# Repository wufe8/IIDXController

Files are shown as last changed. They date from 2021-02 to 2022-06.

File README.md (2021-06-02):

# IIDXController
自制iidx手台记录

## 目录
[TOC]

## 材料
1. 开发板-控制器主控  
    arduino leonardo micro pro 23RMB  
	建议还是加钱上普通的leonardo 也就贵十几二十
2. 面包板以及排母: 分别1个和2个 用于分线以及固定  
    普通的400孔面包板 2.6RMB/个
	2.54mm间距单行排母 1\*12P 0.23RMB/个
3. 按键: 4个白色33mm长按键 3个黑色33mm长按键 4个白色33mm方按键  
    普通 150RMB一套  
    三和 750RMB一套
4. 微动: 11个   
    D2MV-01-1C2 12.8RMB/个   
    D2MV-01-1C3(压力稍大) 12.8RMB/个  
    V-15-1C25(压力较大 常用于辅助键) 4.5RMB/个  
    135RMB
5. 编码器: 1个  
    npn dc5-24v 600p/r的E6B2-CWZ6C 75RMB  
6. 杜邦线: 约50条  
    1pin 2.54mm 0.15RMB/条 
    23RMB
7. 插簧(可选 也可直接焊接): 约30个 用于杜邦线与微动簧片的热插拔连接  
    2.8mm(#187端子) 或 6.3mm(#250端子) 根据使用微动的端子而定 10-15RMB/100个  
    插簧钳 35RMB 也可使用焊接 更牢固 就是比较耗时间
    > 此外 直接定制头是最省时间的方法
8. 游戏机按钮支架(买按键应该有送 不用买)&LED灯(led可选): 各11个  
	0.5-1.5RMB/个
9. 橡胶防滑垫: 4个  
	4个 22(大头)\*18(小头)\*10(高)白色 0.7RMB/个
10. 螺丝  
	4个 M3\*6 手拧 作为1p 2p切换  
	4个 M3\*20 平头 作为转盘距离切换  
	4个 M4\*6 内六角 作为防滑垫固定  
	8个 M3 螺母 备用  
	共约15RMB 有剩余螺丝
11. 外壳  
	cad绘制 5系铝带90度弯折&焊接 280RMB
	如果用单块板子然后热熔胶什么的拼接应该会便宜很多
	加上换成木板或者亚克力 成本应该可以压低至100内

--------
总计813.25RMB 含邮费 含外壳 以及买错的(xh2.54端子线 #110插簧)

> 省钱tips:
> 1. 使用便宜的微动 甚至可能可以节省100RMB以上
> 2. 编码器可以便宜一点 但不建议太缩水 大约可以节省0-35RMB
> 3. 插簧和插簧钳可以不买 使用焊接 可以节省45-55RMB
> 4. 外壳是成本大头 使用铁 塑料 甚至纸箱 可以节省50-280RMB
> 如此 尽可能缩 可能可以到350RMB

## 程序
https://github.com/lizardbeans/diy-iidx
现成开源程序 感谢@lizardbeans 大佬  
不过他提供的是普通leonardo 而我用的是pro micro 接口少些(无法同时使用完整版)  
加上我需要4个功能键 因此对代码进行了些修改(还好代码并不难而且也预料到了加按键这个需求)  
fork: https://github.com/wufe8/diy-iidx

## 贡献者
wufe8

## LICENSE 使用许可
diy-iidx需参照原作者
其余 所有模型(包括blender以及cad)都是我根据网上描述自己画的  
请勿商用 而个人使用没有问题 但如果网络中进行引用 希望可附带本网址(https://github.com/wufe8/IIDXController)

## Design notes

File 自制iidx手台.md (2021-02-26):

# 自制iidx手台记录
wufe8

## 目录
[TOC]

## 材料
1. 开发板-控制器主控
micro pro 21$
2. 按键: 4个白色33mm长按键 3个黑色33mm长按键 4个白色33mm方按键
普通 90$
星韵 150$
三和 750$
3. 弹簧: 13个 20g/60g/80g/90g
djdao 85$/10个
4. 微动: 13个  
D2MV-01-1C2 13$/个
D2MV-01-1C3(压力稍大) 13$/个
V-15-1C25(压力较大 常用于辅助键) 4.5$/个
5. 编码器: 1个
npn dc5-24v 600p/r的E6B2-CWZ6C 75$
6. 端子线: 13条
4pin 2.57mm 0.4$/个
7. 插簧: 13个
2.8mm(#187端子) 或 6.3mm(#250端子) 根据使用微动的端子而定 5$/50个
插簧钳 35$
8. 游戏机按钮支架&LED灯(led可选): 各13个
0.5-1.5$/个
9. 橡胶防滑垫
4个 22(大头)*18(小头)*10(高)白色 0.7$/个
10. 螺丝
4个 M3*6 手拧 作为1p 2p切换
4个 M3*20 平头 作为转盘距离切换
4个 M4*4 内六角 作为防滑垫固定
8个 M3 螺母 备用
共约12$

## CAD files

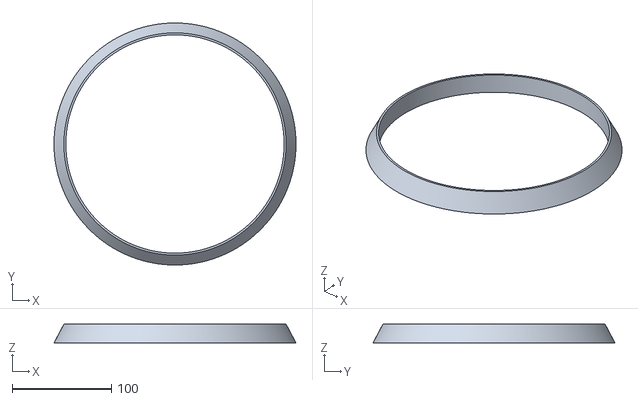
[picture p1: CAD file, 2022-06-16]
TurntableFrame.stl
244.0 x 244.0 x 19.0

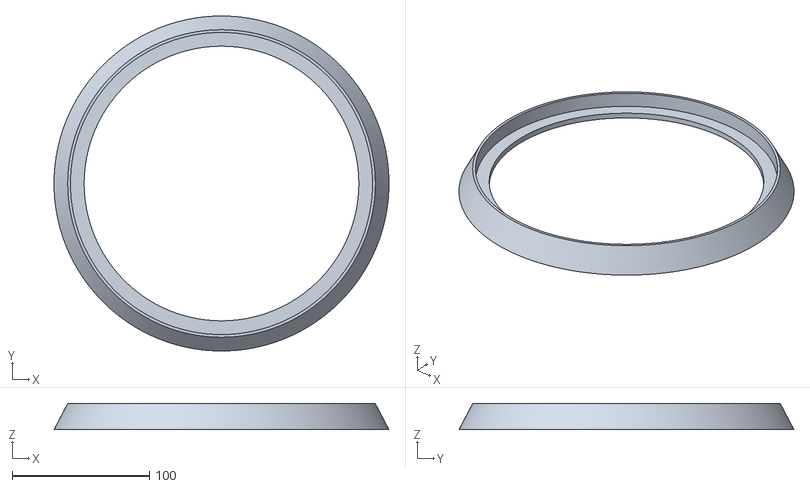
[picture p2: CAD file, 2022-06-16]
TurntableFrame(fixed).stl
244.0 x 244.0 x 19.0

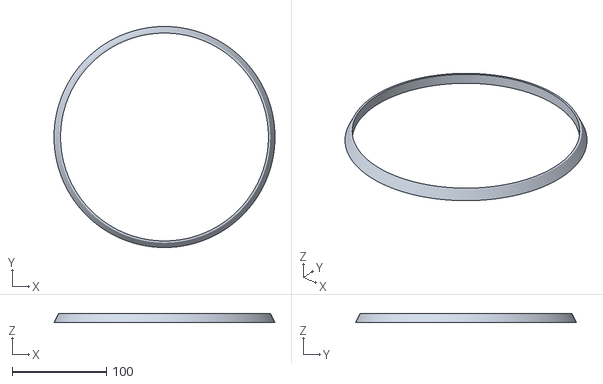
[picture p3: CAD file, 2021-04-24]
TurntableFrame(upper).stl
234.0 x 234.0 x 10.0

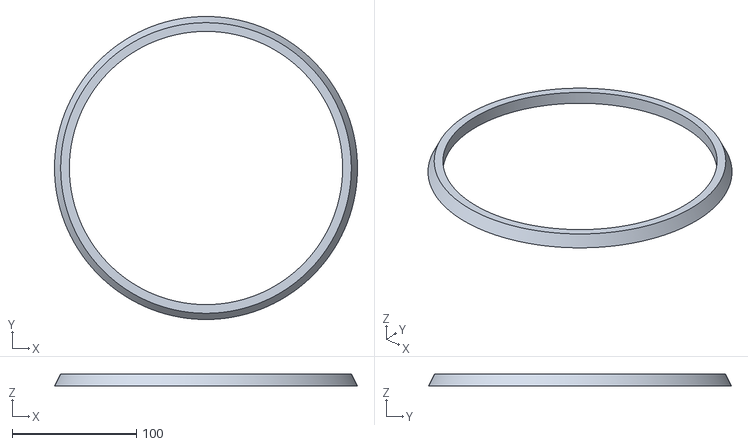
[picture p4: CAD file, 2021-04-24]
TurntableFrame(lower).stl
244.0 x 244.0 x 10.00

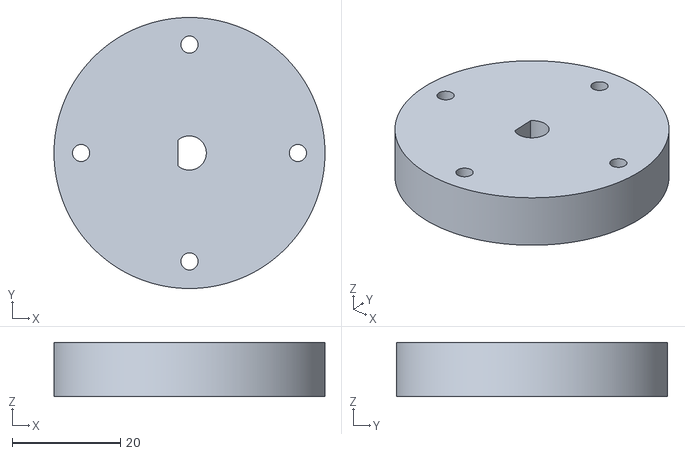
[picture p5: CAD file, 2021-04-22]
EncoderFixed.stl
50.0 x 50.0 x 10.0

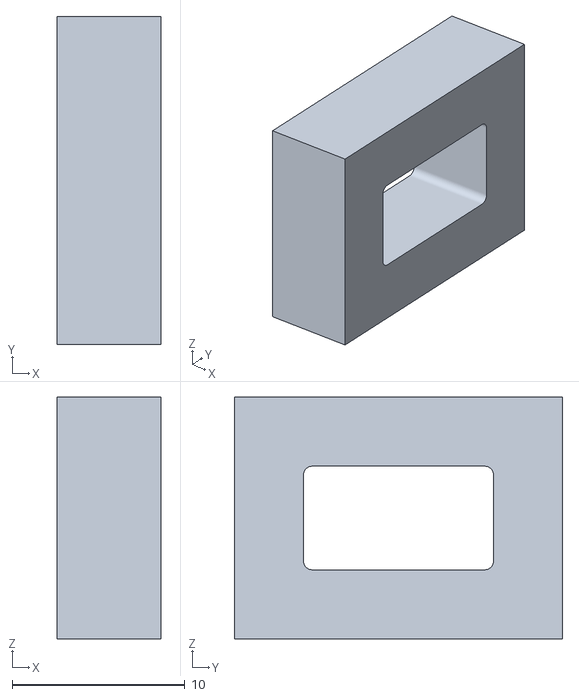
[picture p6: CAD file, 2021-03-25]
USBfixed.stl
6.00 x 19.0 x 14.0

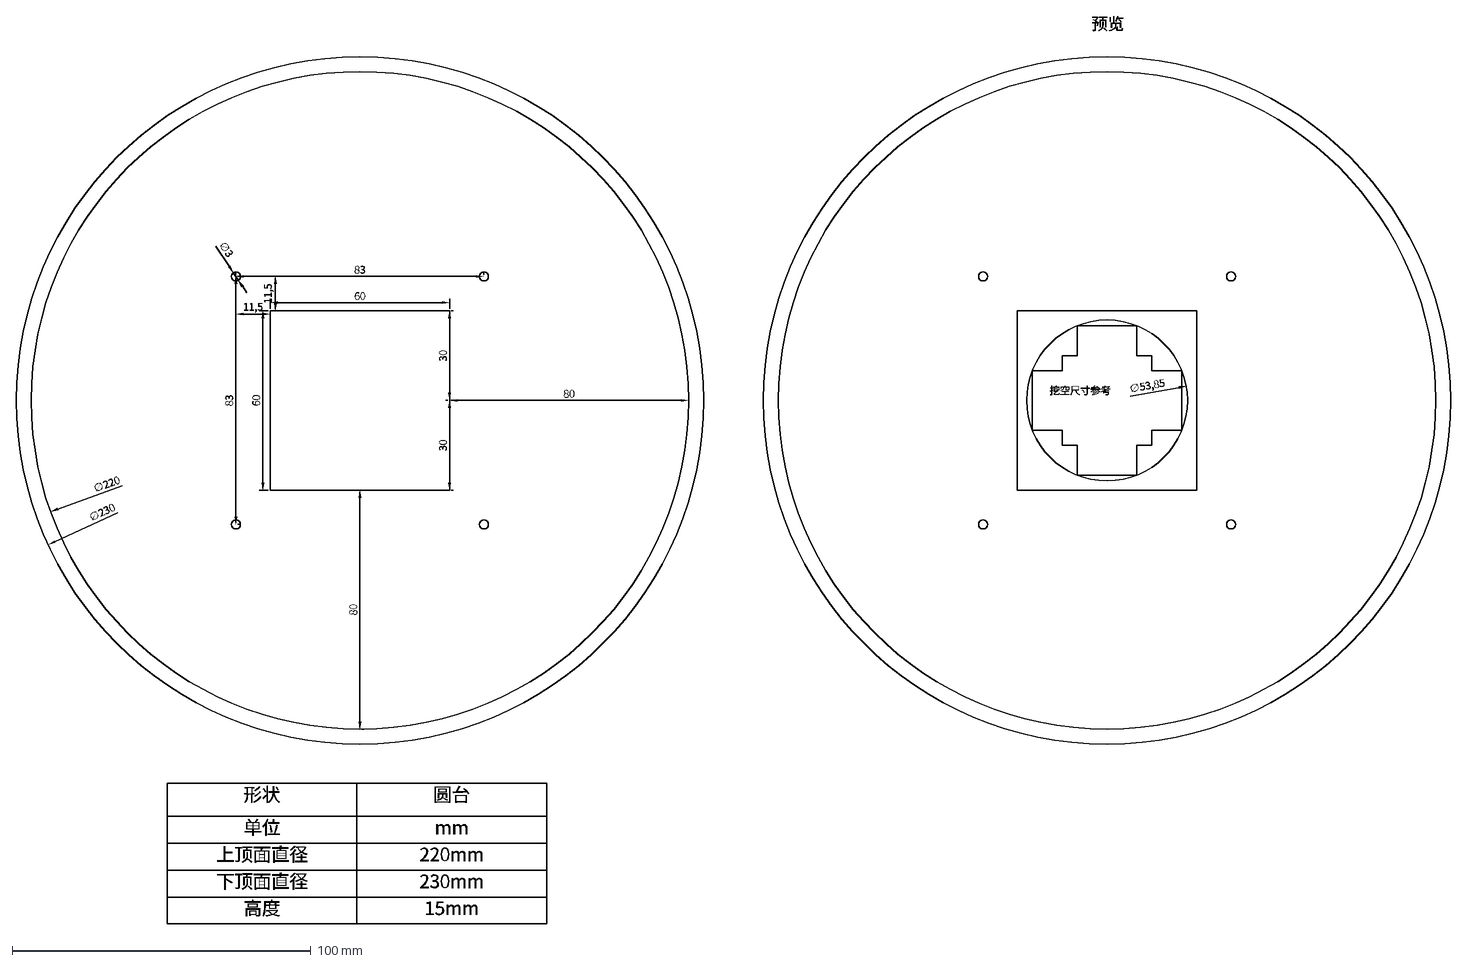
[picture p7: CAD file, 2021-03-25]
TurnTable.dxf
83
∅3
∅220
∅230
形状
圆台
单位
mm
上顶面直径
220mm
下顶面直径
230mm
高度
15mm
预览
80
60
11,5
挖空尺寸参考
∅53,85
30

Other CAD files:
TurnPan(M4).dwg
UpperCover.dwg
LaserTask.dwg
KeyPanel.dwg
BottemPanel.dwg
TurnTable(Cylinder).dwg
TurnPanel.dwg
EncoderLock.dwg
rgbBar.dwg
TurnPan.dwg
EncoderFixed.blend
EncoderFixed.dwg
TurnTable.dwg
TurntableFrame.blend
USBfixed.blend
iidxCase.blend

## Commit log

2021-02-26 预留更大面板误差以及调节编码器开口尺寸 1. 外壳长宽+8mm 2. 键盘区面板长宽+4mm 3. 转盘区面板长宽+4mm 4. 编码器开口从80mm*60mm调节至90mm*50mm > 到手编码器测得直径为40mm 5. 为防止误操作 将拆分动画删除了
    [iidxCase.blend]
2021-02-26 加厚加高外壳 调整接口开孔 整理细节 1. 根据群友提醒 外壳加厚 1mm->2mm 2. 对照源台尺寸 外壳加高 40mm->52mm 3. 调整部分备用(comp)模型没有同步更改的问题 4. 因加高外壳 整理了尺寸数据 现在应该都在准确的位置了 5. 调整上下盖连接框的尺寸 均减小4mm
    [iidxCase.blend]
2021-02-26 增加实际比例的版本(x0.01) 导出面板模型 1. 将部分模型的缩放改为了顶点缩放 保证物体缩放都为x1 避免导出转格式出现问题 2. 实际比例版本为iidxCase(RealSize).blend 3. 导出了键盘区与转盘区的面板模型 stl+dxf
    [KeyPanel.dxf, KeyPanel.stl, TurnPanel.dxf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]
2021-02-26 Update and rename 自制iidx手台.md to README.md
2021-02-27 增加编码器扣具模型
    [EncoderFixed.blend, EncoderFixed.stl, iidxCase.blend]
2021-02-27 调节比例
    [EncoderFixed.blend, EncoderFixed.stl]
2021-02-28 调节键盘区宽度 对应上街机比例 > 经调查 应该是黑键顶部延长与转盘相切 而非黑键中部 1. 据上 调节键盘 以及键盘区尺寸 现在键盘区到边框的宽度和转盘区到边框的宽度一样了 2. 为美观与对齐 将区域至边框的距离改为4mm->5mm 3. 同时转盘底到转盘区边框也因此5mm->4mm 4. 因键盘区比例现在并非正方形 且考虑倒角 将键盘区螺丝距离确认变为相对边框距离xy5mm 5. 类似凤凰台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
    [KeyPanel.dxf, KeyPanel.stl, TurnPanel.dxf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]
2021-02-28 修改并完成倒角 合并上盖 1. 因为实际尺寸以及键盘区螺丝采用手拧(螺丝帽直径5mm)的原因 倒角改为5mm 并且完成了其他部分的倒角 2. 将前后左右顶以及延伸边重做 合并为上盖 3. 调整rgb条长度 使长度同键盘与转盘区
    [KeyPanel.dxf, KeyPanel.stl, TurnPanel.dxf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]
2021-03-01 调节键区到边框的距离 设计准确的cad图纸 1. 为方便设计 调整了键区到边框的距离5mm->4mm(改回来了) 因为4mm的情况下左上边框到转盘开口的距离恰好为10cm 2. 发现转格式大失败 就当建了个模型吧 现在开始使用cad绘图了
    [BottemPanel.dxf, BottemPanel.stl, UpperCover(fix).dwg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]
2021-03-02 添加键盘区cad
    [KeyPanel(fix).dwg]
2021-03-03 完成了上盖 键盘 转盘3块的cad 键盘区对齐 1. 基本完成了上盖(平铺图) 键盘区 转盘区的cad文件 TODO 底盖cad 2. 发现键盘区位置有问题 按键到键盘区边框的距离无法取整 目前对齐转盘区后基本解决 但仍有小数存在
    [BottemPanel.dxf, KeyPanel(fix).dwg, KeyPanel.dxf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]
2021-03-03 解决螺丝孔位置错误 以及背板cad
    [BottemPanel(fix).dwg, KeyPanel(fix).dwg, UpperCover(fix).dwg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]
2021-03-04 完成顶板的3d预览以及底板图纸; blender标记防滑塞位置
    [BottemPanel(fix).dwg, UpperCover(fix).dwg, iidxCase.blend]
2021-03-04 微调cad标记细节 以及补充README.md
    [UpperCover(fix).dwg]
2021-03-05 紧急更新 补充typec挖孔 以及调整键盘间距
    [UpperCover(fix).dwg]
2021-03-06 修复转盘区cad的z轴归零问题;添加了转盘cad
    [TurnPanel(fix).dwg, TurnTable.dwg]
2021-03-06 调节视角
    [TurnTable.dwg]
2021-03-12 修复位置问题 1. 顶盖应留空键盘区以适用1/2p切换 2. 根据加工方意见 顶底螺丝直径加大 M3->M4 3. 为防止转盘固定件卡边框 扩大转盘抬高圆台中心的挖空尺寸 50mm->60mm 4. 键盘区上下应为14mm(10mm) 而非24mm
    [KeyPanel(fix).dwg, TurnPanel(fix).dwg, TurnTable.dwg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]
2021-03-16 add no mark version dwg; add TurnPan and rgbBar
    [KeyPanel(no-mark).dwg, TurnPan(no-mark).dwg, TurnPan.dwg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]
2021-03-19 conform panel to be laser cut; add encoder fixed part
    [EncoderLock.dwg, KeyPanel(no-mark).dwg, LaserTask.dwg]
2021-03-19 rename no-mark -> real, retention error
    [EncoderFixed.blend, EncoderFixed.stl, EncoderLock.blend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]
2021-03-25 rebuild EncoderFixed and TurnTable
    [EncoderFixed.blend, EncoderFixed.stl, TurnTable.dwg]
2021-03-25 调整尺寸标记 对齐整数坐标 以及扩大typec开口
    1. 删除*(real)版本(不含参数标记的) 但保留并重新整合"LaserTask.dwg"
    2. 编码器固定决定也使用切割 故重建"EncoderLock.blend" -> "EncoderLock.dwg"
    3. TurnPanel.dwg 调整尺寸标记 对齐整数坐标
    4. TurnTable.dwg 修正参考图形的高度(15mm) 对齐整数坐标
    5. UpperCover.dwg 根据实际测试 扩大typec开口(9*2.6 -> 9*2.7); 重建参考图形
    6. rgbBar.dwg 调整尺寸标记
    [EncoderLock.blend, EncoderLock.dwg, EncoderLock.stl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]
2021-03-25 导出TurnTable.dxf; 以及LaserTash.wmf
    [LaserTask.dwg, TurnTable.dxf]
2021-03-25 增加供3d打印的转盘垫高外壳stl;以及圆柱型的转盘垫高cad
    [TurnTable(Cylinder).dwg, TurntableFrame(lower).stl, TurntableFrame(upper).stl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]
2021-03-25 调整转盘上下外框高度
    [TurntableFrame(lower).stl, TurntableFrame(upper).stl, TurntableFrame.blend]
2021-03-26 将转盘柱体加入激光雕刻任务中
    [LaserTask.dwg]
2021-03-29 UpperCover 提高5mm 实测原58mm仅刚好可塞入按键
    [UpperCover.dwg]
2021-04-07 重大失误: 盘距错误 114.5mm->90mm, 94.5mm -> 70mm
    [UpperCover.dwg]
2021-04-12 add LaserTask-turntable
2021-04-19 将编码器-转盘固定件重做为高面数 圆形
    [EncoderFixed.blend, EncoderFixed.stl]
2021-04-21 将外壳高度提高至7cm
    [UpperCover.dwg]
2021-04-22 更新转盘区域打印件 1. EncoderFixed挖孔扩大1.05倍以应对公差 2. EncoderFixed的螺丝孔穿过底面以兼容螺丝+螺母的固定方式 3. TurntableFrame提高高度 1.8cm->2cm 并同时提供完整包含上下部分的stl文件
    [EncoderFixed.blend, EncoderFixed.stl, TurntableFrame(lower).stl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]
2021-04-24 调整转盘边框缩放 放大10倍
    [TurntableFrame(lower).stl, TurntableFrame(upper).stl, TurntableFrame.blend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]
2021-05-01 回滚至原盘距并微调盘距 1. 订正盘距错误 盘距应为最靠近转盘的按键挖孔至转盘切线的距离 原盘距基本无误(原为按键边框 应-2mm) 故回滚同时92mm->90ms 2. 回滚时根据后续提交 将上壳高度提升至7cm 3. 因盘距-2mm 上壳与下盖宽度也-2mm 520mm->518mm 4. 补充下盖距离标记
    [BottemPanel.dwg, UpperCover.dwg]
2021-05-11 调整键距 1. 键距应为挖孔间距 而非按键边框间距 故长宽距离各缩短4mm 2. 应上变更 调整面板尺寸 使黑键上端与转盘中心平齐 且延长并保持按键与边框距离固定 21mm->23mm 3. 调整外壳按键挖空与螺丝孔的位置以适应新按键面板 4. 缩短外壳宽度 518mm->508mm 保持面板至边框均为4mm 5. 降低数据线挖孔高度(降低6mm) 至顶面距离29mm->35mm 方便内部走线 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
    [BottemPanel.dwg, KeyPanel.dwg, LaserTask.dwg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]
2021-05-25 删除上盖的中部rgb挖孔(填充困难)
    [UpperCover.dwg]
2021-06-02 更新readme
2022-02-16 release v1.0 1. 铝材质用 添加M4螺丝版本的TurnPan.dwf 盘直径为219mm 2. 扩大usb口 现为9.3*3.5mm（标准为8.3*2.5mm）
    [TurnPan(M4).dwg, UpperCover.dwg]
2022-03-05 补充外壳blender动画
    [iidxCase.blend]
2022-06-16 1.添加cad版编码器固定件(但实际打样遇到内圈过大导致螺丝未锁紧时无法咬合的问题) 2. 改进转盘边框 添加内固定高4mm 深10mm 边框降低1mm高度(20mm->19mm)
    [EncoderFixed.dwg, TurntableFrame(fixed).stl, TurntableFrame.blend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]
